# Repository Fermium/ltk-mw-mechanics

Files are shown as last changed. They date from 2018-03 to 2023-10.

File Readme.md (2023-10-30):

# Free Open Scientific Equipment

Fermium LTD announces the free release of all scientific equipment designs under the terms of the MIT license. You are free to use them as you wish.

## Why?

Our small business is no longer competitive in this sector, and thus we've ceased production of this scientific equipment.

## What's Included

- Microwave Optics Kit:
  - [Microwave RX and TX](https://github.com/Fermium/ltk-mw-electronic): A pair of ultra-low-cost 10GHz microwave transmitters and receivers
  - [Microwave Kit Display](https://github.com/Fermium/frm-mw-display)
  - [Diode Detector](https://github.com/Fermium/frm-mw-diode-detector): A 10GHz diode detector for studying evanescent waves and wave propagation in waveguides
  - [Mechanics](https://github.com/Fermium/ltk-mw-mechanics) including:
    - [Transmitter and Receiver](https://github.com/Fermium/ltk-mw-mechanics/tree/master/transmitter%20and%20receiver) with rear protractor
    - [Structure](https://github.com/Fermium/ltk-mw-mechanics/tree/master/structure) with feet, rulers, center protractor, and center mount
    - [PCB Optics Components](https://github.com/Fermium/ltk-mw-mechanics/tree/master/pcbs): Mirrors, polarizers, photon-sieves, Fresnel zone plates
    - [Waveguides](https://github.com/Fermium/ltk-mw-mechanics/tree/master/accessories/waveguides)

- Hall Effect Apparatus:
  - [Electronics](https://github.com/Fermium/ltk-hall-electronics) for the 2015, 2017, and 2019 models
  - [2015 Firmware](https://github.com/Fermium/Hall-firmware)
  - [2017 Firmware](https://github.com/Fermium/hall-firmware-v2#hall-effect-apparatus-firmware---2017)

# ltk-mw-mechanics

Mechanical parts for the Microwave Optics Kit. Almost all mechanical designs are provided in Siemens NX format. All PCBs in Altium Designer format.

## Main unit

The main unit is defined in the folder [structure](ltk-mw-mechanics/structure) and it includes a center protractor, the joint, feet, rulers, device mount.

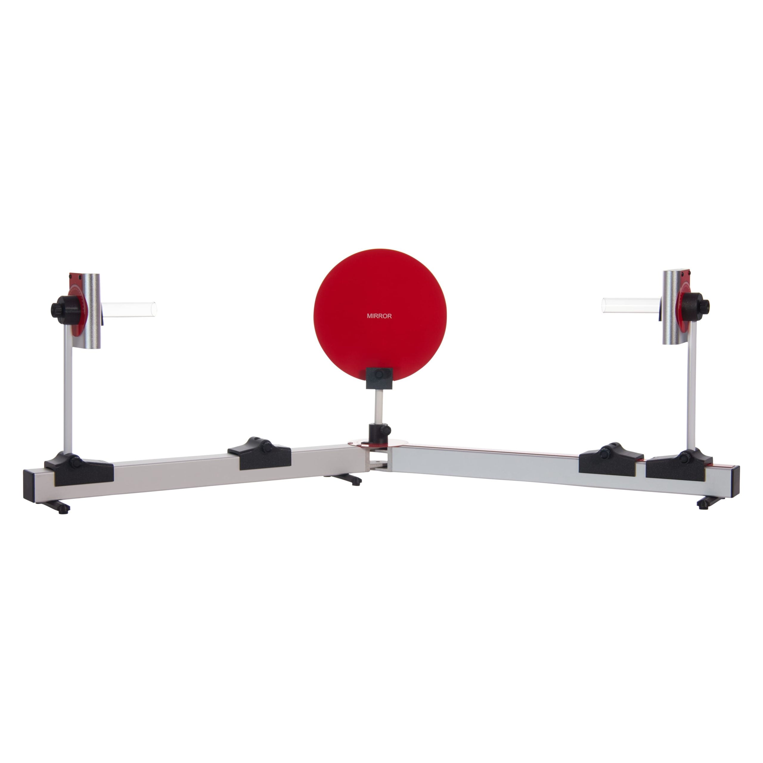
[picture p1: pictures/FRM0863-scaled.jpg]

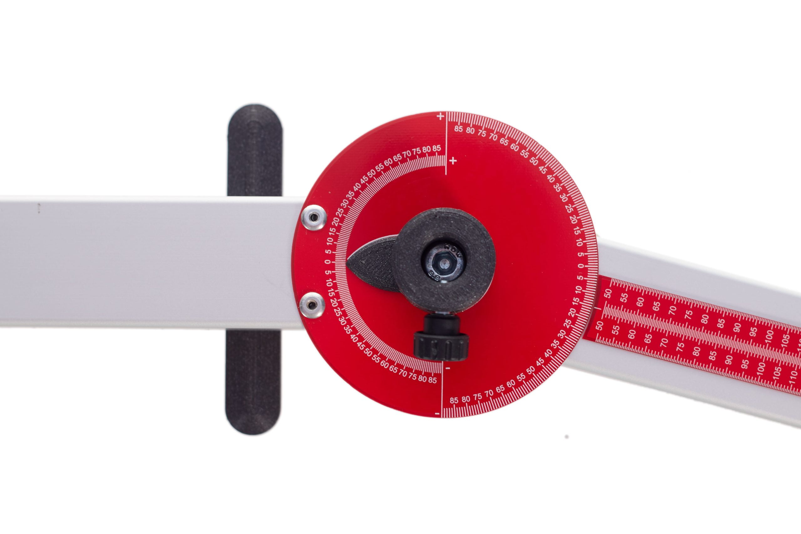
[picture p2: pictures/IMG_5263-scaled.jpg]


The protractors are under the folder pcbs.

## Optical components

Optical components are defined in the folder [pcbs](ltk-mw-mechanics/pcbs) and they include:

- [Double slot](ltk-mw-mechanics/pcbs/ltk_mw_double_slot.PcbDoc)
- [Fresnel zone plate](ltk-mw-mechanics/pcbs/ltk_mw_fresnel_plates.PcbDoc)
- [Mirror](ltk-mw-mechanics/pcbs/ltk-mw_mirror.PcbDoc)
- [Photon Sieve](ltk-mw-mechanics/pcbs/ltk-mw_photon_sieve.PcbDoc)
- [Polarizer](ltk-mw-mechanics/pcbs/ltk-mw_polarizer.PcbDoc)

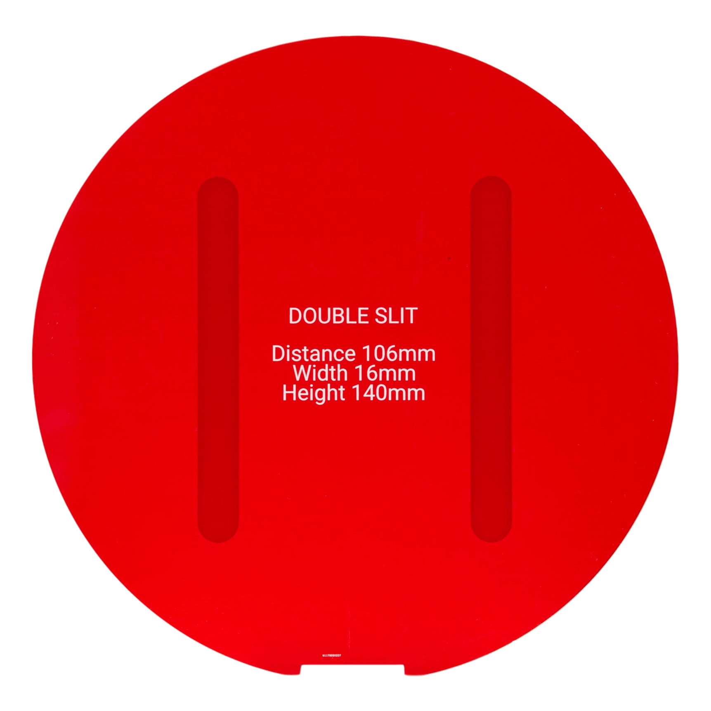
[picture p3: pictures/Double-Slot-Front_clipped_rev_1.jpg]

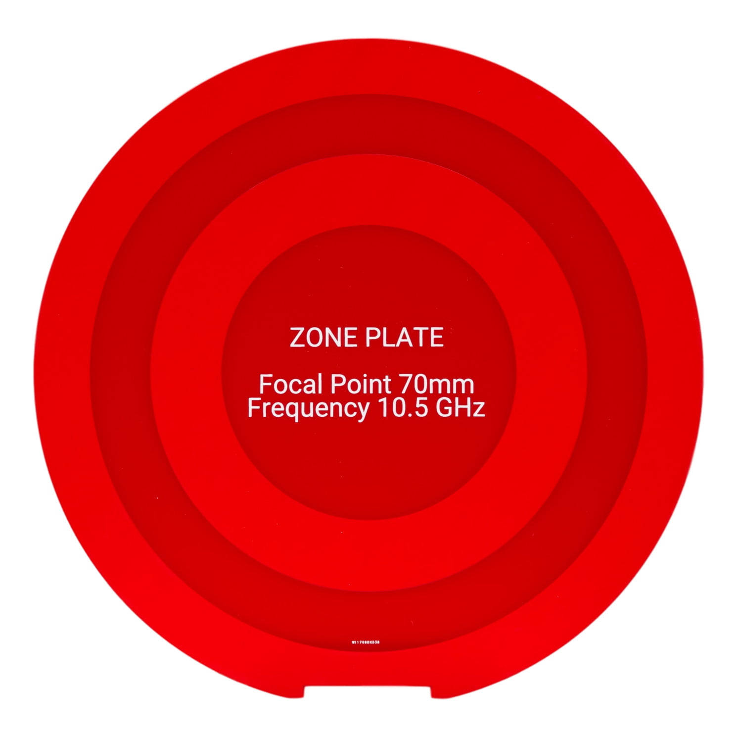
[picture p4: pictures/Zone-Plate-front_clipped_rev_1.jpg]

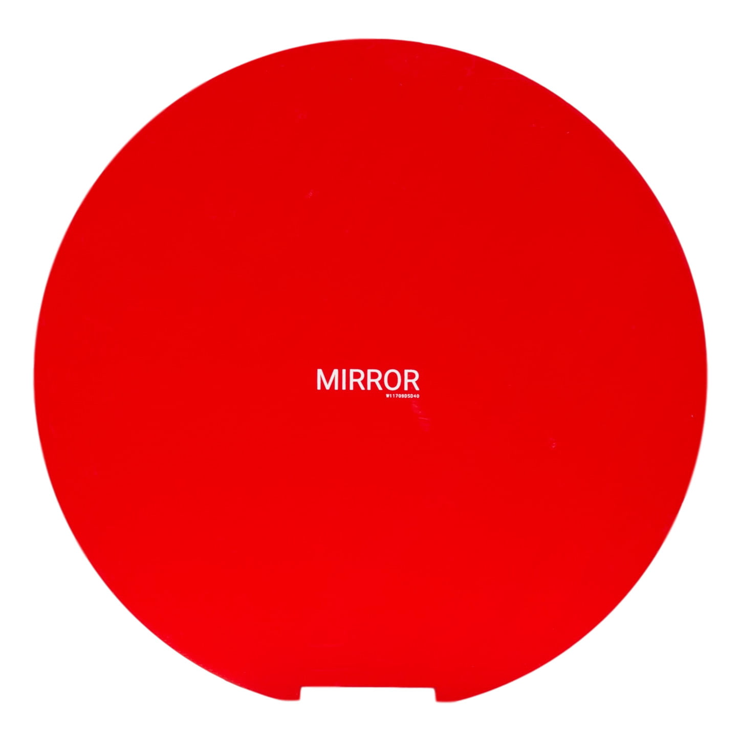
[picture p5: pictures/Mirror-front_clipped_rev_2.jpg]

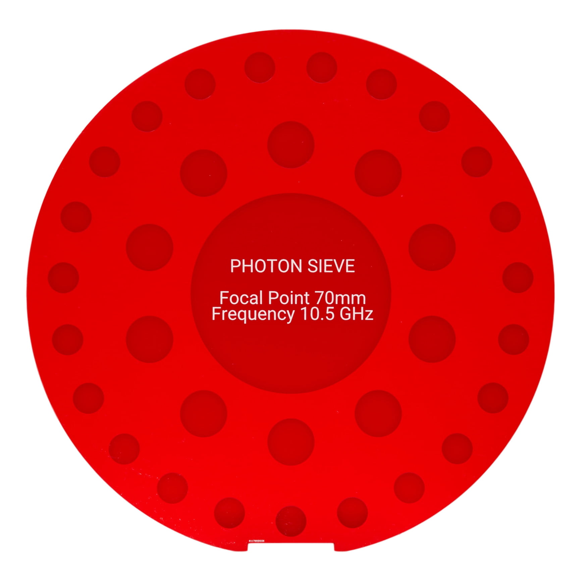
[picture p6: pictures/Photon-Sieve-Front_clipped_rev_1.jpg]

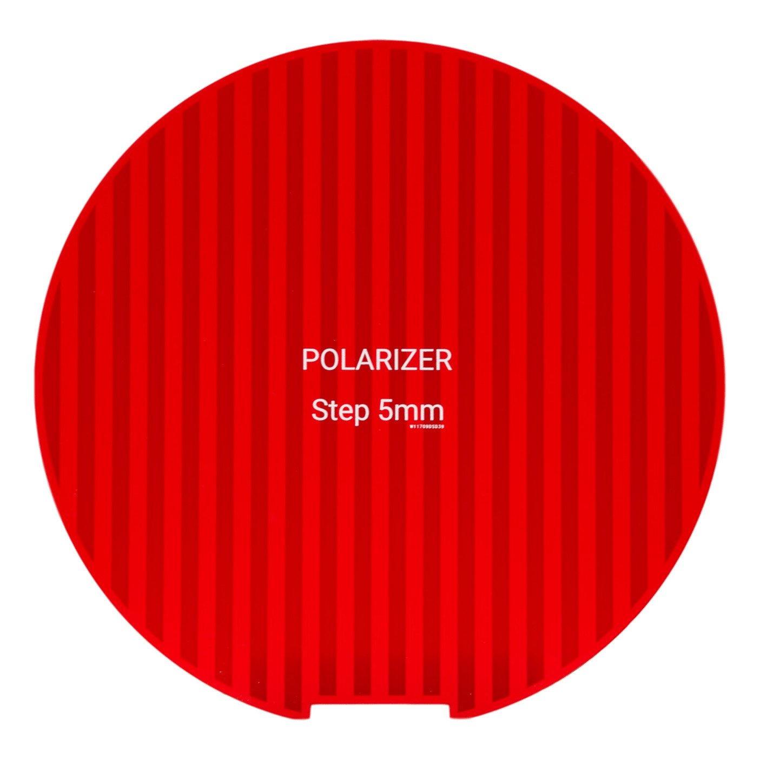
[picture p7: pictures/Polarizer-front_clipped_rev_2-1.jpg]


A classical fresnel lens is also included in another folder.

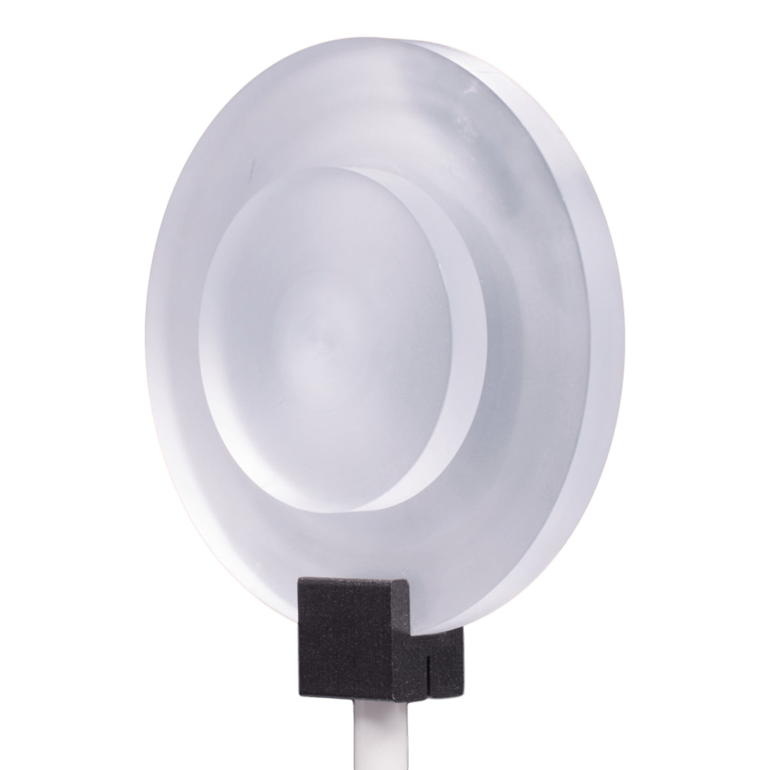
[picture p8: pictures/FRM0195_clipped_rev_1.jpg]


## RX and TX

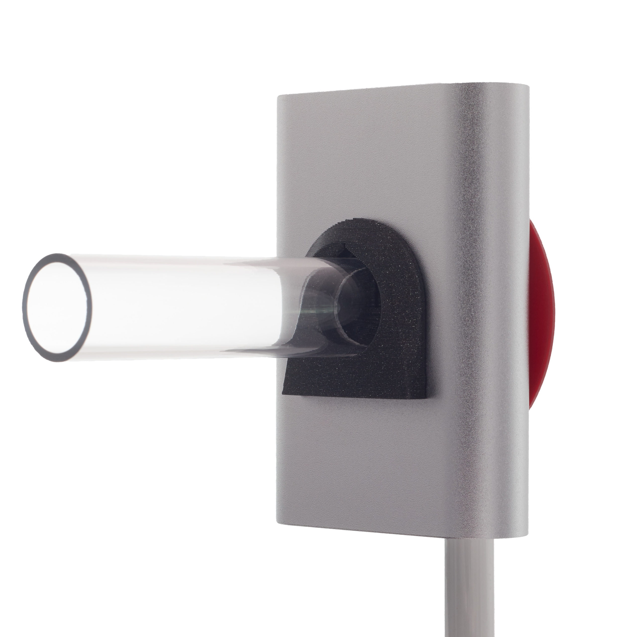
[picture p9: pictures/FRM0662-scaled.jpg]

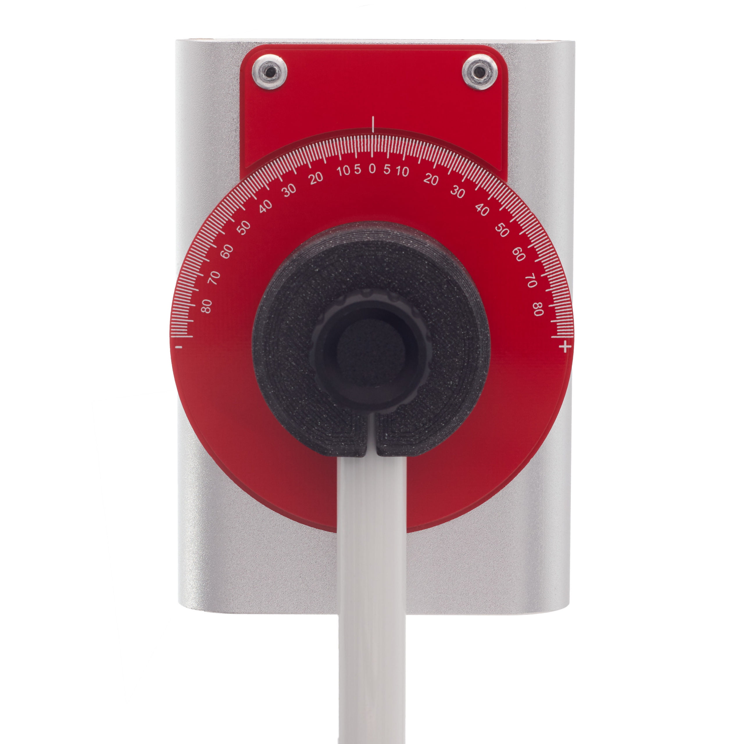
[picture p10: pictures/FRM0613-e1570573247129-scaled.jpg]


## Others

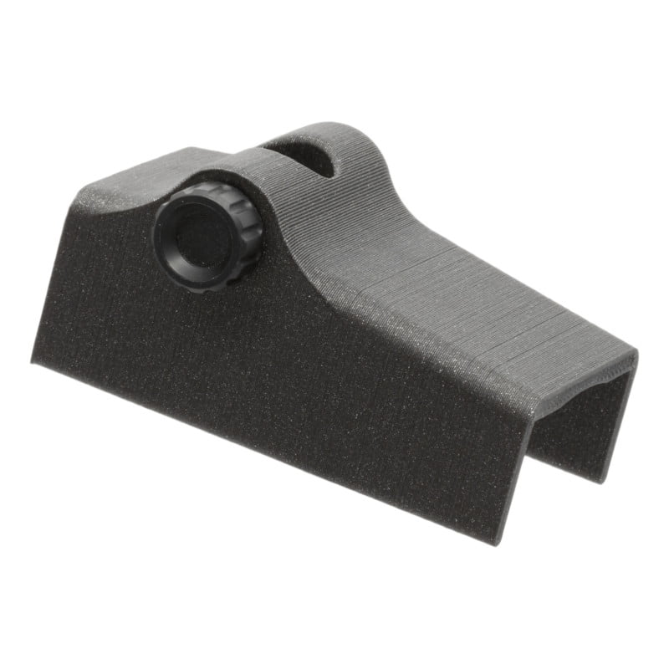
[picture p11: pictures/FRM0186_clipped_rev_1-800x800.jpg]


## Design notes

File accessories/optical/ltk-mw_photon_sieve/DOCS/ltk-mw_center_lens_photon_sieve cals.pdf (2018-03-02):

Created with Swift Calcs Free Public Edition.
Worksheet is limited to non-commercial use.
Accelerate your engineering design and analysis at www.swiftcalcs.com.

## ltk-mw_center_lens_photon_sieve cals

1
c ≡ 299792458 ·
1 s

1 m

2 | ƒrequency ≡ 10.525 GHz
3 | λ ≡ requency c ƒ

4
| Focal distance:
5 | ƒ ≡ 70 mm
| Where to place the center of the holes:
6 | r n
(n) ≡ (2 · n · λ · + n
| 2
- λ

2

) √ | ƒ

Where are the classical FZP transitions: (useful for center pinhole

7
r
nfre sne l
(n) ≡
(

n · λ · + 4

n

2
- λ

2
)

√
ƒ

Correction factor to increase holes diameter. This can be calculated, but for now i'll take 1.53 for granted (from "Photon sieve space telescope", Andersen, Dearborn, McHang)

≡ 1.53

8 c ƒ

Zone width for the Nth bright zone. In our case, this is also the diameter of the hole.

9 w
n
(n) ≡
2 · rn

(n)

λ ·
- c

ƒ
ƒ

The number of holes, separated by a fixed distance: (relative width makes more beautiful drawings)

≡ Use fixed spacing
- Use relative width spacing
10 | SpacingMethod |
| ≡ 3
11 | holes
sep | mm
≡ 1

12 holes
sepP
13 | variable name | ≡ mixture
14 | mass or moles | of No substance Specified
15 | variable name | ≡ mixture
16 | mass or moles | of No substance Specified
17 | if | SpacingMethod = 0

18
Nhole s
(n) ≡ round
(

3.14 · wn
(n) + hole s
s ep

2 · rn

(n)
)

end

elseif | SpacingMethod = 1
19 | Nhole s
(n) ≡ round
(

3.14 · wn
(n) + wn
(n) · hole s
s epP

2 · rn

(n)
)

20
fusion 360
end

21

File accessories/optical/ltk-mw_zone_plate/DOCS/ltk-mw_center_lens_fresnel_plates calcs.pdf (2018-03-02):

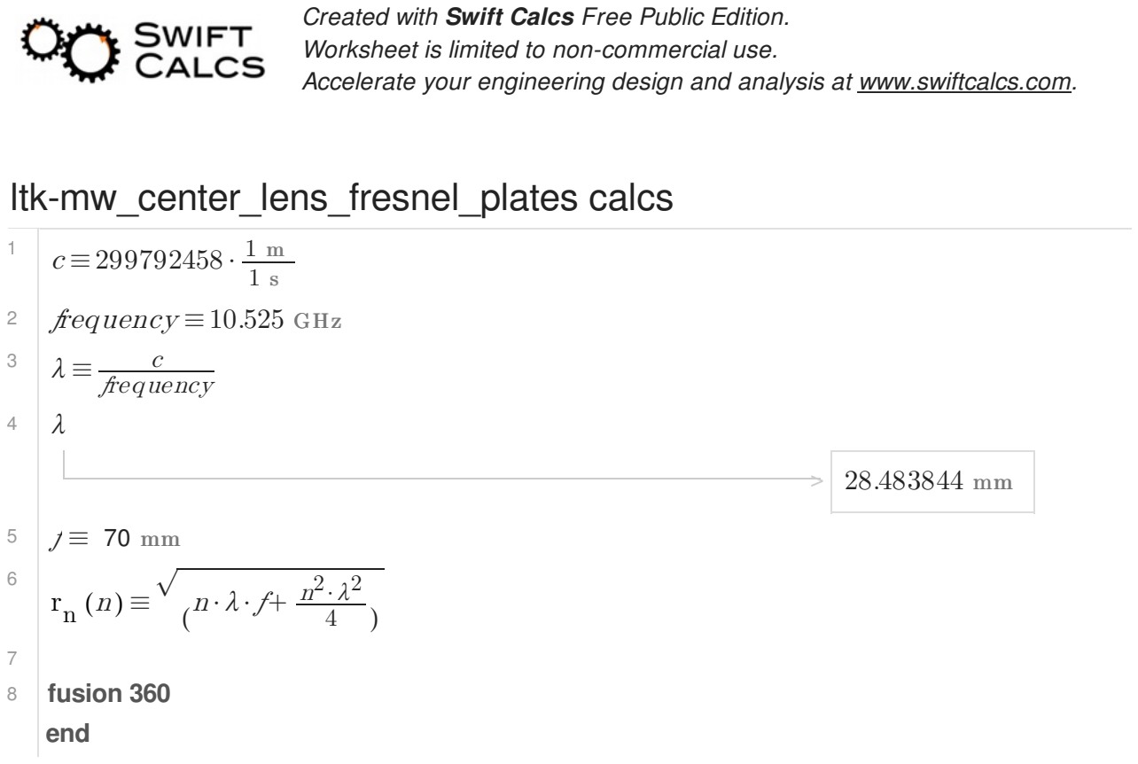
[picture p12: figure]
ltk-mw_center_lens_fresnel_plates calcs; ƒrequency ≡ 10.525 GHz; requency; fusion 360 end

Created with Swift Calcs Free Public Edition.
Worksheet is limited to non-commercial use.
Accelerate your engineering design and analysis at www.swiftcalcs.com.

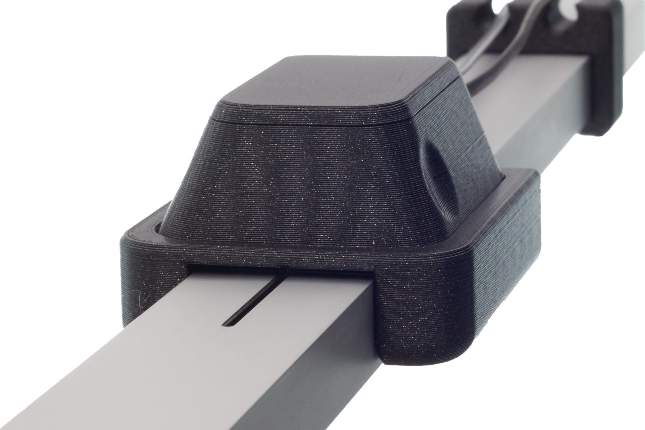
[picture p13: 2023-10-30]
pictures/FRM0453-scaled.jpg

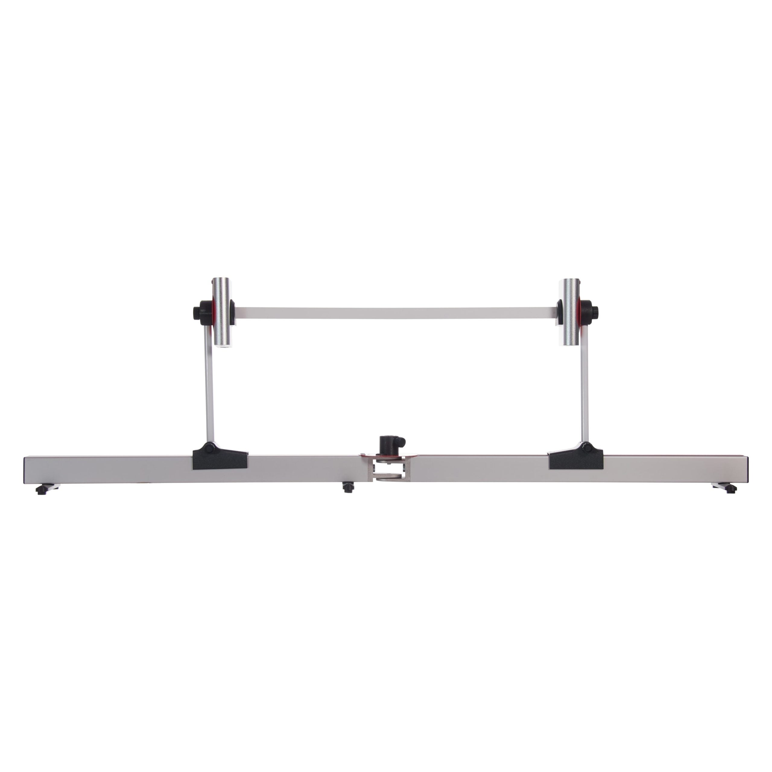
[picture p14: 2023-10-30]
pictures/IMG_5238-scaled.jpg

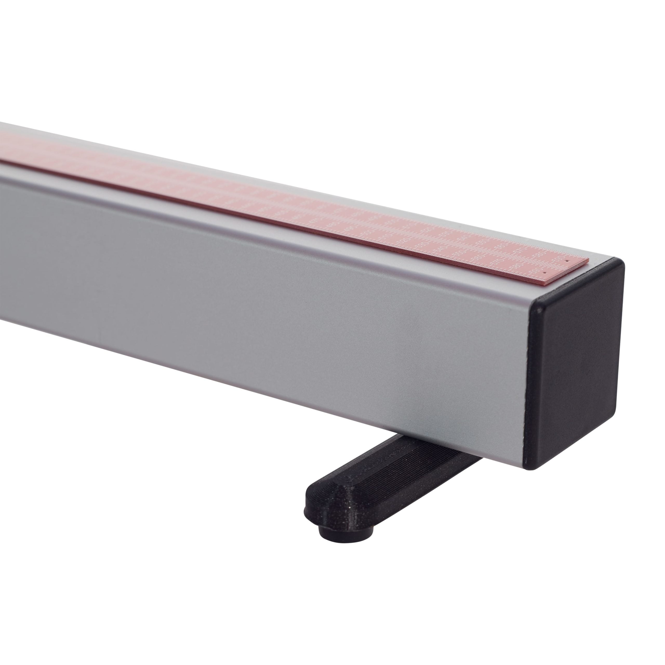
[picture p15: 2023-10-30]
pictures/IMG_5254-scaled.jpg

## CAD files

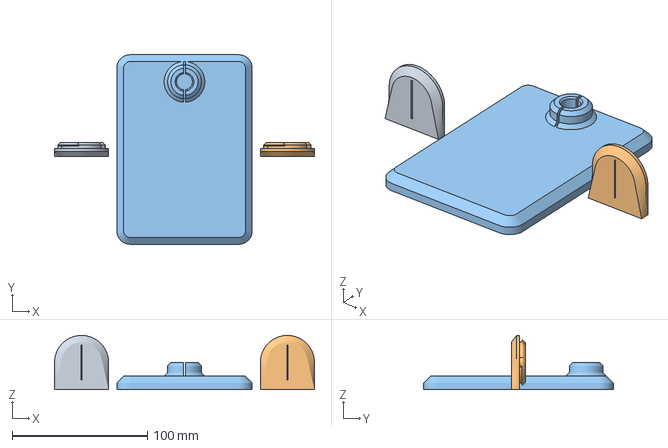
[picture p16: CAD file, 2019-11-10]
3DP Platters/ltk-mw_thin_waveguide_kit.3mf
192.0 x 140.0 x 40.0 mm
ltk-mw_thin_waveguide_holder.stl
table_slider.stl

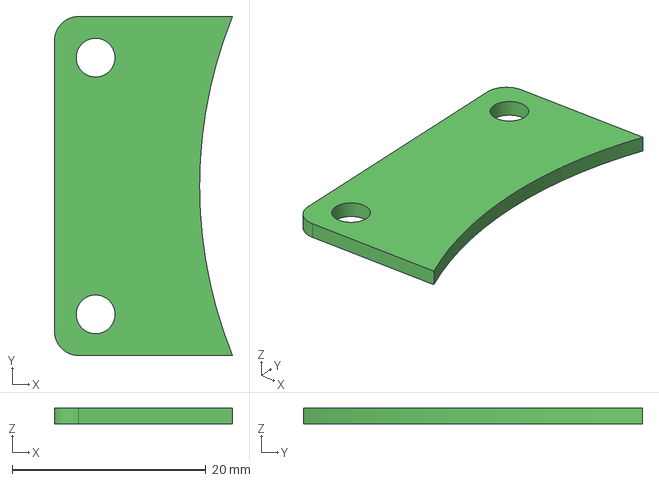
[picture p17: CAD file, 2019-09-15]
pcbs/exports/center_index/ltk-mw_center_index.step
18.4 x 35.0 x 1.62 mm

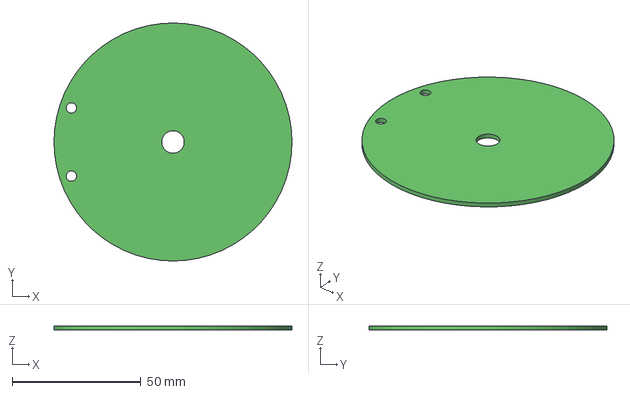
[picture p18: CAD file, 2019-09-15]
pcbs/exports/center_protractor/ltk-mw_center_protractor.step
92.5 x 92.5 x 1.62 mm

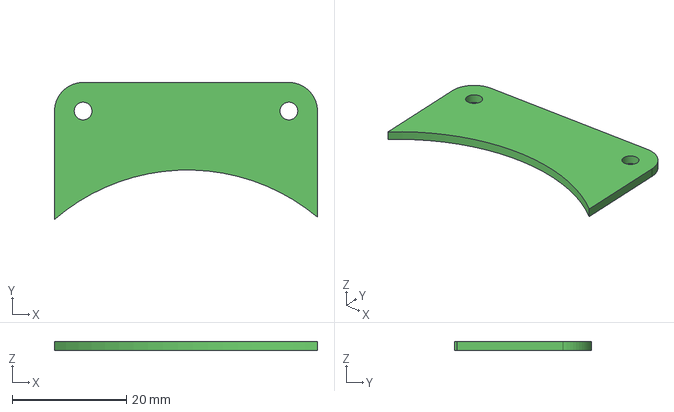
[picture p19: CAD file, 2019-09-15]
pcbs/exports/device_index/ltk-mw_device_index.step
46.0 x 24.0 x 1.60 mm

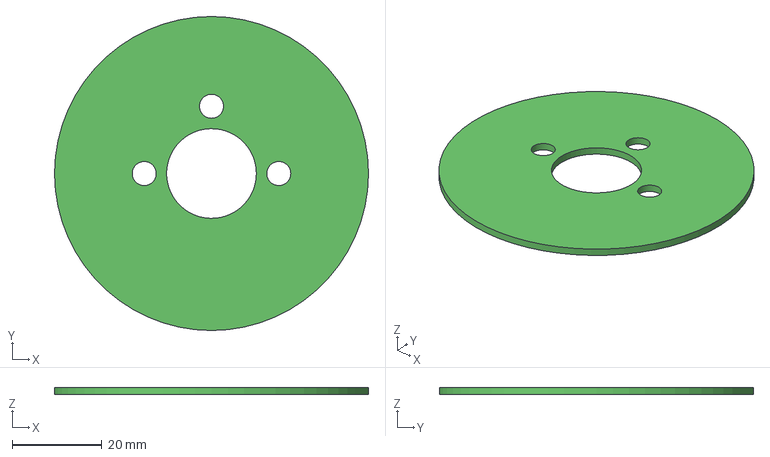
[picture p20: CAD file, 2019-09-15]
pcbs/exports/device_protractor/ltk-mw_device_protractor.step
70.0 x 70.0 x 1.62 mm

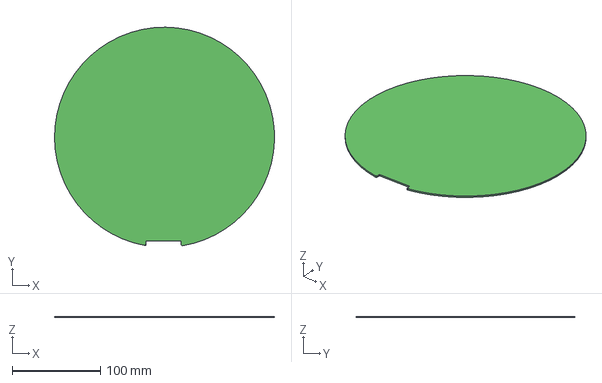
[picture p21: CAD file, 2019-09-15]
pcbs/exports/double_slot/ltk_mw_double_slot.step
249.9 x 248.4 x 1.62 mm

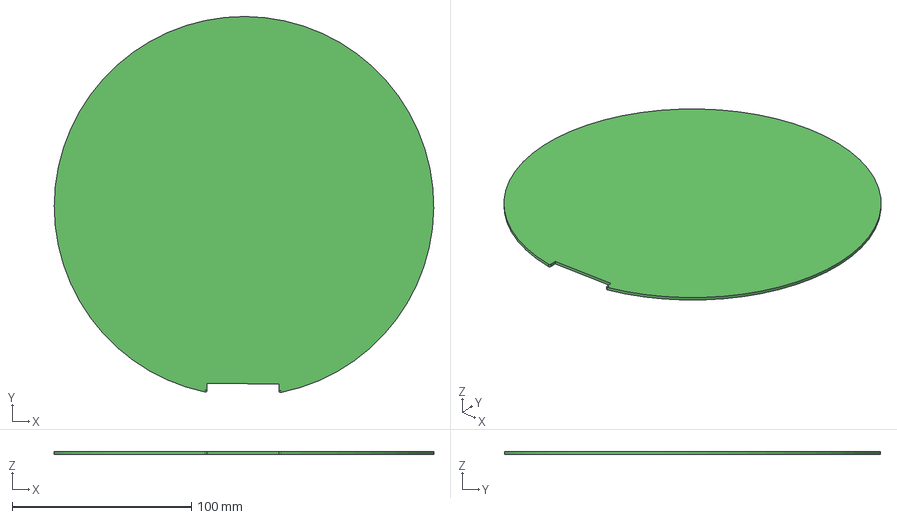
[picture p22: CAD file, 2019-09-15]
pcbs/exports/fresnel_plates/ltk_mw_fresnel_plates.step
211.9 x 209.8 x 1.62 mm

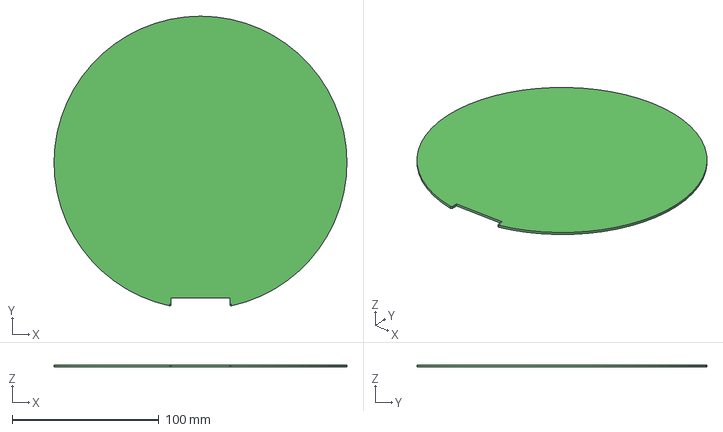
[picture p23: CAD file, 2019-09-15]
pcbs/exports/mirror/ltk-mw_mirror.step
200.0 x 197.7 x 1.62 mm

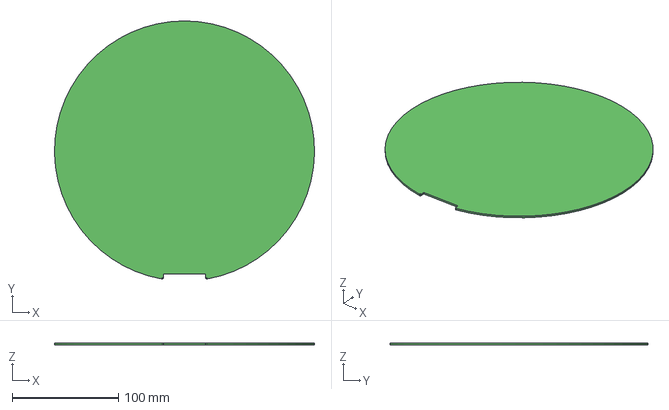
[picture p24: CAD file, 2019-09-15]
pcbs/exports/photon_sieve/ltk-mw_photon_sieve.step
245.2 x 243.4 x 1.62 mm

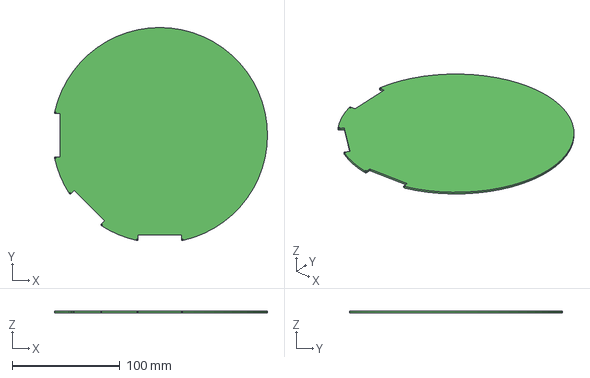
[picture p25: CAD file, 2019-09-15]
pcbs/exports/polarizer/ltk-mw_polarizer.step
197.7 x 197.7 x 1.62 mm

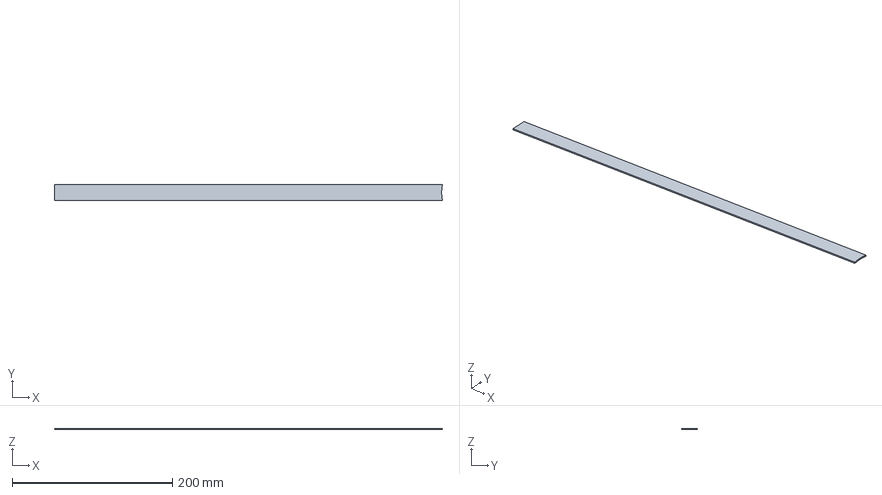
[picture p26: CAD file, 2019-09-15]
pcbs/exports/ruler/ltk-mw_ruler.step
484.3 x 20.0 x 1.60 mm

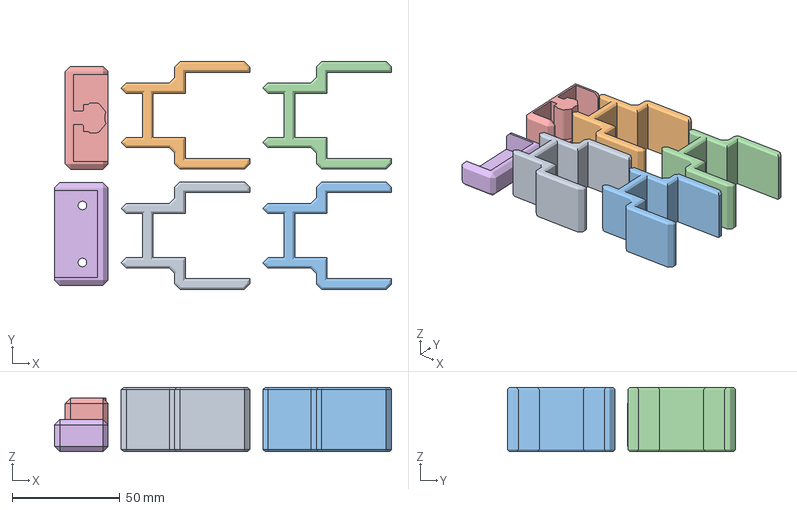
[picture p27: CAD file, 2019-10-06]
3DP Platters/ltk-mw_manufacturing_aids.3mf
156.8 x 106.0 x 30.0 mm
ruler_adhesive_positioning_jig.stl
ltk-mw_dima_foro_profilati.stl_1
ltk-mw_dima_foro_profilati.stl_2

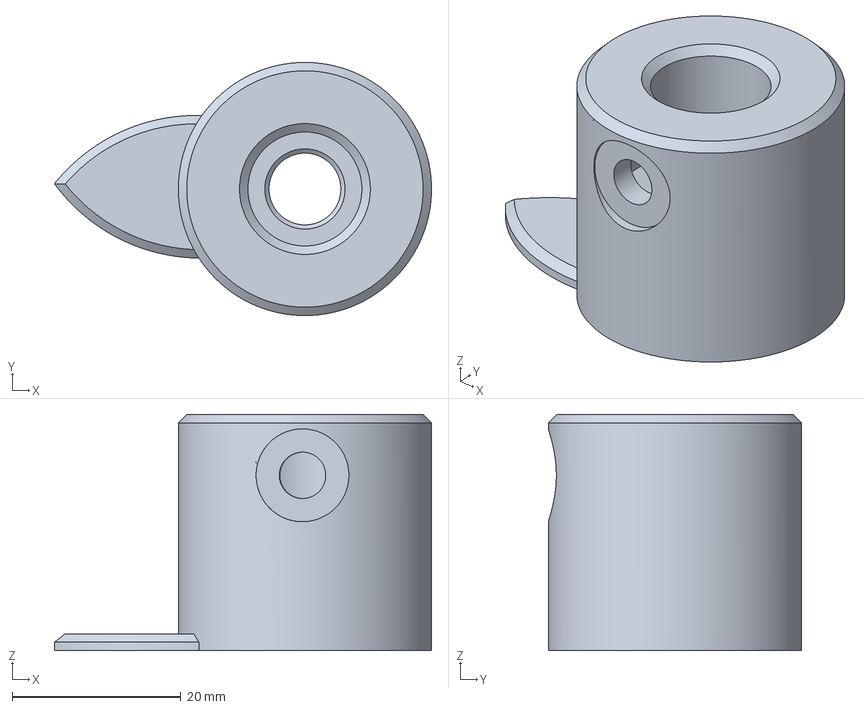
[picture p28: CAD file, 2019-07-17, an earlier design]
3DP Platters/OLD/ltk-mw_center_index.3mf
44.7 x 30.0 x 28.0 mm

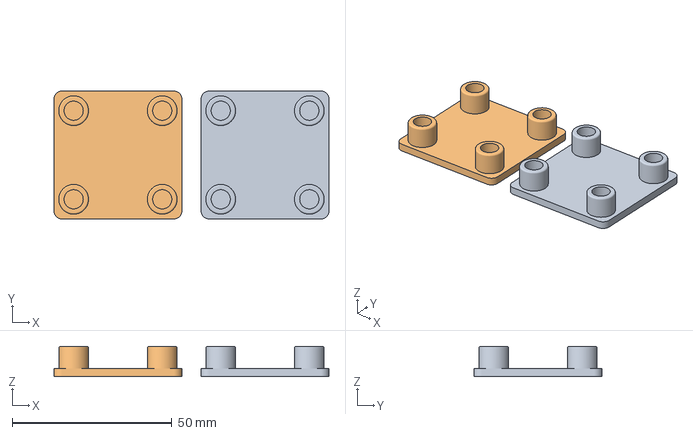
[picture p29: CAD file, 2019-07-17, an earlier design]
3DP Platters/OLD/084_201_024.3mf
86.0 x 40.0 x 9.50 mm

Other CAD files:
3DP Platters/OLD/ltk-mw_device_fulcrum_0.3mm_PLA_MK3.3mf
3DP Platters/OLD/ltk-mw_sliders_0.3mm_PLA_MK3.3mf
3DP Platters/OLD/ltk-mw_foot_3dp_0.3mm_PLA_MK3.3mf
3DP Platters/OLD/ltk-mw_vice_3dp_0.3mm_PLA_MK3.3mf
3DP Platters/OLD/antenna_holder_0.15mm_PLA_MK3.3mf
3DP Platters/OLD/ltk-mw_surplus_lens_1_0.3mm_PLA_MK3.3mf
3DP Platters/OLD/prism.3mf
accessories/optical/ltk-mw_double_slit/ltk-mw_double_slit.prt
accessories/optical/ltk-mw_mirror/ltk-mw_mirror.prt
accessories/optical/ltk-mw_photon_sieve/ltk-mw_photon_sieve.prt
accessories/optical/ltk-mw_polarizer/ltk-mw_polarizer.prt
accessories/optical/ltk-mw_prism/prism.prt
accessories/optical/ltk-mw_surplus_lens/ltk-mw_surplus_lens_1.prt
accessories/optical/ltk-mw_zone_plate/ltk-mw_zone_plate.prt
accessories/sliders/OLD/HI_BN 124 1090658 hexagon jam nut B M5.prt
accessories/sliders/OLD/HI_BN 1984 2052520 hexagon nut M5.prt
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

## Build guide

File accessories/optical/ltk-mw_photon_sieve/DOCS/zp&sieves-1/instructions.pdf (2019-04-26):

## How to Make a Zone Plate, Photon Sieve or Pinhole Sieve

### By Guillermo Peñate

Use the following tools and instructions to make your own zone plate, photon sieve or pinhole sieve. The tools and instructions are included in the zip file below.

Download: http://www.pinholeday.org/support/docs/Zone_Plate_and_Sieves/zp&sieves-1.zip

Once you have downloaded and unzipped the file, follow these instructions:

1. Decide which type of "lens" you want to print: Zone Plate, Pinhole Sieve or Photon Sieve.

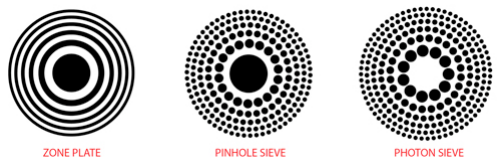
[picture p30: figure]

2. Using a text editor, like Microsoft's Notepad or equivalent, open the corresponding PostScript file (zoneplate.ps, pinholesieve.ps or photonsieve.ps).
3. Change the parameter as indicated in the Postscript code. For instance, to change the focal length of the "lens" to 80mm, you will change the number in the following line:

/F 75 def % change the number to whatever focal length in mm you want

to

/F 80 def % change the number to whatever focal length in mm you want

Note that 75 is the value the file has after being downloaded, once you have changed it and if you save the edited file onto itself, it will keep that new number until you change it again. Feel free experimenting changing the other values as indicated in the Postscript file itself.

4. Save the *.ps file, I suggest you keep the original file intact and save your modified file with a different name to something meaningful, for instance: ZP80mm64.5.ps meaning Zone Plate 80mm f/64 +1/2 stops.
5. Print your modified file.

You will need a program capable of printing Postscript files. I used PDFCreator, this program takes the *.ps file and convert it to PDF, that you can easily print. PDFCreator is free. Photoshop is also capable of printing *.ps files. I have also been told that a Mac computer recognizes postscript (*.ps) files without the need of any extra application.

6. Do not scale down or up when printing the file, otherwise the printed "lens" will not have the correct size.
7. At the bottom of the printed "lens" there is some self explanatory information. For your convenience, the distance you should place your SLR camera from the printed "lens" is indicated (in millimeters) as: "Distance to SLR's lens".
8. Place your SLR at the same height of your printed "lens", and the film plane of the SLR parallel to this printed "lens".

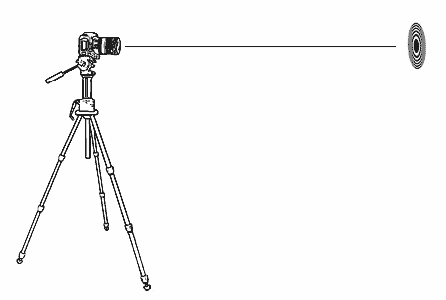
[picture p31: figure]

9. Some SLRs, particularly those with "spot metering capabilities" have in their viewfinder a circle that indicates the spot meter area:

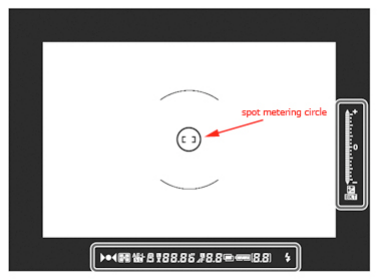
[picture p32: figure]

This spot meter circle has a diameter that for each camera model should be indicated in its User's Guide Manual. We could use a compass to draw a circle on a piece of paper that has a diameter equal to the diameter of the spot meter circle in the viewfinder times the magnification used to print the "lens" and then place the camera at a distance such that the spot meter circle on the view finder overlaps it exactly. For example, in a Nikon F801s, also known as N8008s, the spot meter circle is 3.5mm in diameter, if we have used 30 as the magnification to print the "lens", we would need to draw a circle 105mm in diameter (3.5x30), place this circle on the same place we would later place the printed "lens" and make the spot meter circle in the viewfinder match exactly this 105mm circle.

10. Obviously, use the highest contrast B&W film possible and process it using equally high contrast chemicals.

Copyright © 2012 Guillermo Peñate • File was last modified: April 11 2012 11:42:52.

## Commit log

2018-03-09 fixed missing exports
    [ltk-mw_center_disc_200mm.GBL, ltk-mw_center_disc_200mm.GBO, ltk-mw_center_disc_200mm.GBP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]
2018-04-09 Aggiunti goniometri
    [ltk-mw_center_protractor.GBL, ltk-mw_center_protractor.GBO, ltk-mw_center_protractor.GBP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]
2018-04-09 Added varius support files
    [conventional-protractor.dxf, device-protractor.dwg, device-protractor.dxf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]
2018-04-13 Daphne you ask, i fix shit mylady
    [ltk-mw_device_protractor.PcbDoc, project.PrjPCB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]
2019-04-26 added center index, cleaning, updating outjob
    [conventional-protractor.dxf, device-protractor.dwg, device-protractor.dxf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]
2019-04-26 moved the whole mechanics in this repo
    [001031842.prt, 001033088.prt, 001034287.prt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]
2019-07-16 Added 3DP stuff
    [084_201_024.3mf, antenna_holder_0.15mm_PLA_MK3.3mf, ltk-mw_center_index.3mf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]
2019-07-17 cleanup 3dp
    [084_201_024.3mf, antenna_holder_0.15mm_PLA_MK3.3mf, ltk-mw_center_index.3mf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]
2019-07-17 New lids for txrx enclosure, added waveguides
    [3183882_INOX_A4.prt, AEH119.prt, AEH119_assy.prt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]
2019-07-19 Antenna holder printability tweaks part one
    [antenna_holder.prt, assy_AEH119.prt, ltk-mw_main_assy.prt]
2019-07-19 Drawings, new antenna holder drafter out
    [001034287.prt, AEH119.prt, AEH119_assy.prt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]
2019-07-25 Lid and antenna holder are ready
    [AEH119_assy.prt, AEH119_lid_bottom.prt, antenna_holder.prt]
2019-07-25 New ruler, new device protractor index, resolved various pcb issues, updated various pcbs, exported everything
    [AEH119.prt, AEH119_assy.prt, AEH119_lid_bottom.prt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]
2019-07-25 fixed ruler exports
    [ltk-mw_center_index.DWG, ltk-mw_center_index.step, ltk-mw_center_protractor.DWG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]
2019-07-26 much tweaking, exported with fab3000
    [ltk-mw_center_index.DWG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]
2019-07-26 updated ruler and drawings
    [ltk-mw_aluminium_profile_dx.prt, ltk-mw_aluminium_profile_sn.prt, ltk-mw_center_index.DWG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]
2019-07-27 Added small holes to make fab house happy
    [ltk-mw_center_index.DWG, ltk-mw_center_index.PcbDoc, ltk-mw_center_index.step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]
2019-07-27 Everything is now 2layer
    [ltk-mw_center_index.DWG, ltk-mw_center_index.PcbDoc, ltk-mw_center_index.step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]
2019-07-27 small fixes to pcb
    [ltk-mw_center_index.DWG, ltk-mw_center_index.step, ltk-mw_center_protractor.DWG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]
2019-07-27 Added text for JLCPCB code number
    [ltk-mw_center_index.DWG, ltk-mw_center_index.PcbDoc, ltk-mw_center_index.step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]
2019-08-06 Added elesa+ganter knob to txrx
    [AEH119_assy.prt, ELESA_GANTER_6551.prt, assy_AEH119.prt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]
2019-09-15 upgraded ruler, removed protractor index, fixed device index
    [1004565_Stahl_8_8.prt, AEH119.prt, AEH119_assy.prt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]
2019-09-16 fixed fucking device index fulcrum fffff
    [assy_AEH119.prt, ltk-mw_device_fulcrum.prt, ltk-mw_main_assy.prt]
2019-11-10 thicker sliders
    [ltk-mw_slider_3dp.prt, ltk-mw_slider_dx_3dp.prt, ltk-mw_slider_sn_3dp.prt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]
